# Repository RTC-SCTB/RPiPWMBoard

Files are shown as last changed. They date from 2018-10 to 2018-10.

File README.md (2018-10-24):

# RPiPWM_Board
## Описание
Проект платы расширения для одноплатного компьютера Raspberry Pi (версии B+, 2B, 3B, с 40 пинами).    
Включает в себя PCA9685 - I2C генератор ШИМ сигнала на 16 каналов, и либо одноканальным АЦП MCP3221, для измерения 
напряжения аккумулятора, либо измерителя питания INA219, который позволяет измерять также протекающий ток.  
Предусмотрен преобразователь напряжения LM2596-5.0 для питания Raspberry Pi от аккумулятора, 
номинальное напряжение питания до 25 В, при превышении возможен выход из строя некоторых (или всех) компонентов.  
Предусмотрено место для EEPROM CAT24C32 с обвязкой - для использования технологии 
[Raspberry Pi HAT](https://www.raspberrypi.org/blog/introducing-raspberry-pi-hats/), 
однако данная технология пока не используется.

## Содержание
- Необходимые нестандартные библиотеки - в папке `Libraries`  
- Список изменений - в файле `Changes.md`
- Gerber файлы - в папке `Gerbers`

## Функции

- Питание Raspberry Pi от аккумулятора (напряжение аккумулятора не должно превышать 25 В);
- Создание ШИМ сигнала на 16 каналах (0 - 15). Каналы 0 - 11 имеют возможность подключения внешнего источника питания
(предназначены для управления сервоприводами), каналы 12 - 15 предназначены для подключения драйверов, которые
 генерируют свое напряжение на данном разъеме;
- Определение напряжения питания (при подключении через клеммы), с помощью одноканального АЦП;
- Подключение I2C OLED дисплея SSD1306 размером 128x32 пикселя (может запаиваться на плату). Либо это посадочное место
может использоваться для подключения других I2C устройств при помощи разъема с шагом 2.54 мм;
- Кнопка и светодиод, подключенные к GPIO Raspberry Pi, функционал для которых может задаваться пользователем;

## Использование
Для данной платы написан [модуль](https://github.com/RTC-SCTB/RPiPWM) на языке Python 3,
реализующий весь перечисленный функционал.

## Полезные ссылки
- Даташит для ШИМ контроллера [PCA9685](https://cdn-shop.adafruit.com/datasheets/PCA9685.pdf)
- Даташит для дисплея [SSD1306](https://cdn-shop.adafruit.com/datasheets/SSD1306.pdf)
- Даташит для АЦП [MCP3221](http://ww1.microchip.com/downloads/en/DeviceDoc/20001732E.pdf)
- Даташит для измерителя питания [INA219](http://www.ti.com/lit/ds/symlink/ina219.pdf)

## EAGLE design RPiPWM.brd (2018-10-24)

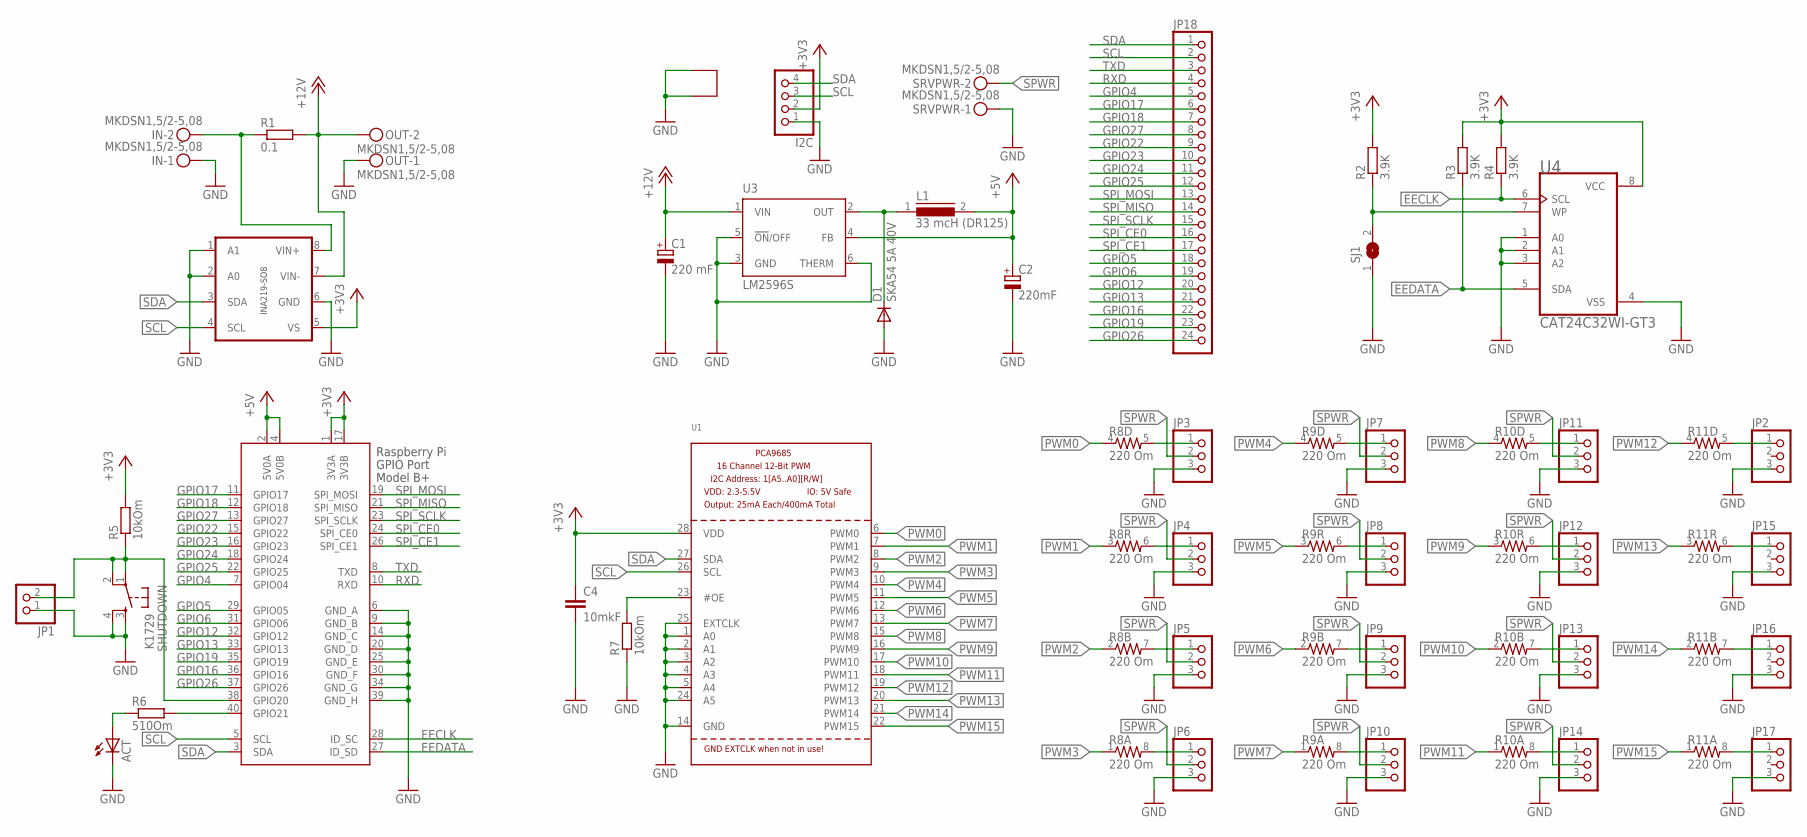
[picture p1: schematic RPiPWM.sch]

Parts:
ACT: LEDCHIPLED_1206; CHIPLED_1206
C1: 220 mF; 140CLH-1014
C2: 220mF; 140CLH-1014
C4: 10mkF; C0805K
D1: SKA54 5A 40V; SMB
GNDLOOP: LOOP
I2C: PINHD-1X04_2.54-S; 1X04-S
IN: MKDSN1,5/2-5,08
JP1: PINHD-1X02_2.54-S; 1X02-S
JP2, JP3, JP4, JP5, JP6, JP7, JP8, JP9, JP10, JP11, JP12, JP13, JP14, JP15, JP16, JP17: PINHD-1X03_2.54-S; 1X03-S
JP18: PINHD-1X24_2.54-S; 1X24-S
L1: 33 mcH (DR125); DR125
OUT: MKDSN1,5/2-5,08
R1: 0.1; R2512
R2, R3, R4: 3.9K; R0805
R5, R7: 10kOm; R0805
R6: 510Om; R0805
R8, R9, R10, R11: 220 Om; 0603-ARV
SHUTDOWN: K1729; DTSM-6
SJ1: SJ
SRVPWR: MKDSN1,5/2-5,08
U1: PCA9685; TSSOP28
U2: INA219-SO8D; SO08
U3: LM2596S; TO263-5
U4: CAT24C32WI-GT3; SOIC127P600X175-8N
X1: RASPI_BOARD_B+#_HDC; RASPI_BOARD_B+HAT_DF_CF

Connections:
+3V3: C4.1, I2C.2, R2.2, R3.2, R4.2, R5.2, U1.28 (VDD), U2.5 (VS), U4.8 (VCC), X1.1 (3V3A), X1.17 (3V3B)
+5V: C2.+, L1.2, U3.4 (FB), X1.2 (5V0A), X1.4 (5V0B)
+12V: C1.+, OUT.2, R1.2, U2.7 (VIN-), U3.1 (VIN)
EECLK: R4.1, U4.6 (SCL), X1.28 (ID_SC)
EEDATA: R3.1, U4.5 (SDA), X1.27 (ID_SD)
GND: ACT.C, C1.-, C2.-, C4.2, D1.A, GNDLOOP.P$1 (1), GNDLOOP.P$2 (2), I2C.1, IN.1, JP1.1, JP2.3, JP3.3, JP4.3, JP5.3, JP6.3, JP7.3, JP8.3, JP9.3, JP10.3, JP11.3, JP12.3, JP13.3, JP14.3, JP15.3, JP16.3, JP17.3, OUT.1, R7.1, SHUTDOWN.3, SHUTDOWN.4, SJ1.1, SRVPWR.1, U1.1 (A0), U1.2 (A1), U1.3 (A2), U1.4 (A3), U1.5 (A4), U1.14 (GND), U1.24 (A5), U1.25 (EXTCLK), U2.1 (A1), U2.2 (A0), U2.6 (GND), U3.3 (GND), U3.5 (!ON!/OFF), U3.6 (THERM), U4.1 (A0), U4.2 (A1), U4.3 (A2), U4.4 (VSS), X1.6 (GND_A), X1.9 (GND_B), X1.14 (GND_C), X1.20 (GND_D), X1.25 (GND_E), X1.30 (GND_F), X1.34 (GND_G), X1.39 (GND_H)
GPIO4: JP18.5, X1.7 (GPIO04)
GPIO5: JP18.18, X1.29 (GPIO05)
GPIO6: JP18.19, X1.31 (GPIO06)
GPIO12: JP18.20, X1.32 (GPIO12)
GPIO13: JP18.21, X1.33 (GPIO13)
GPIO16: JP18.22, X1.36 (GPIO16)
GPIO17: JP18.6, X1.11 (GPIO17)
GPIO18: JP18.7, X1.12 (GPIO18)
GPIO19: JP18.23, X1.35 (GPIO19)
GPIO22: JP18.9, X1.15 (GPIO22)
GPIO23: JP18.10, X1.16 (GPIO23)
GPIO24: JP18.11, X1.18 (GPIO24)
GPIO25: JP18.12, X1.22 (GPIO25)
GPIO26: JP18.24, X1.37 (GPIO26)
GPIO27: JP18.8, X1.13 (GPIO27)
unnamed: R6.2, X1.40 (GPIO21)
unnamed: ACT.A, R6.1
unnamed: D1.C, L1.1, U3.2 (OUT)
unnamed: JP1.2, R5.1, SHUTDOWN.1, SHUTDOWN.2, X1.38 (GPIO20)
unnamed: JP3.1, R8.5 (2)
unnamed: JP4.1, R8.6 (2)
unnamed: JP7.1, R9.5 (2)
unnamed: JP5.1, R8.7 (2)
unnamed: R2.1, SJ1.2, U4.7 (WP)
unnamed: JP6.1, R8.8 (2)
unnamed: JP11.1, R10.5 (2)
unnamed: JP2.1, R11.5 (2)
unnamed: JP15.1, R11.6 (2)
unnamed: JP16.1, R11.7 (2)
unnamed: JP17.1, R11.8 (2)
unnamed: JP14.1, R10.8 (2)
unnamed: JP13.1, R10.7 (2)
unnamed: JP12.1, R10.6 (2)
unnamed: JP8.1, R9.6 (2)
unnamed: JP9.1, R9.7 (2)
unnamed: JP10.1, R9.8 (2)
unnamed: IN.2, R1.1, U2.8 (VIN+)
unnamed: R7.2, U1.23 (#OE)
PWM0: R8.4 (1), U1.6 (PWM0)
PWM1: R8.3 (1), U1.7 (PWM1)
PWM2: R8.2 (1), U1.8 (PWM2)
PWM3: R8.1, U1.9 (PWM3)
PWM4: R9.4 (1), U1.10 (PWM4)
PWM5: R9.3 (1), U1.11 (PWM5)
PWM6: R9.2 (1), U1.12 (PWM6)
PWM7: R9.1, U1.13 (PWM7)
PWM8: R10.4 (1), U1.15 (PWM8)
PWM9: R10.3 (1), U1.16 (PWM9)
PWM10: R10.2 (1), U1.17 (PWM10)
PWM11: R10.1, U1.18 (PWM11)
PWM12: R11.4 (1), U1.19 (PWM12)
PWM13: R11.3 (1), U1.20 (PWM13)
PWM14: R11.2 (1), U1.21 (PWM14)
PWM15: R11.1, U1.22 (PWM15)
RXD: JP18.4, X1.10 (RXD)
SCL: I2C.3, JP18.2, U1.26 (SCL), U2.4 (SCL), X1.5 (SCL)
SDA: I2C.4, JP18.1, U1.27 (SDA), U2.3 (SDA), X1.3 (SDA)
SPI_CE0: JP18.16, X1.24 (SPI_CE0)
SPI_CE1: JP18.17, X1.26 (SPI_CE1)
SPI_MISO: JP18.14, X1.21 (SPI_MISO)
SPI_MOSI: JP18.13, X1.19 (SPI_MOSI)
SPI_SCLK: JP18.15, X1.23 (SPI_SCLK)
SPWR: JP3.2, JP4.2, JP5.2, JP6.2, JP7.2, JP8.2, JP9.2, JP10.2, JP11.2, JP12.2, JP13.2, JP14.2, SRVPWR.2
TXD: JP18.3, X1.8 (TXD)

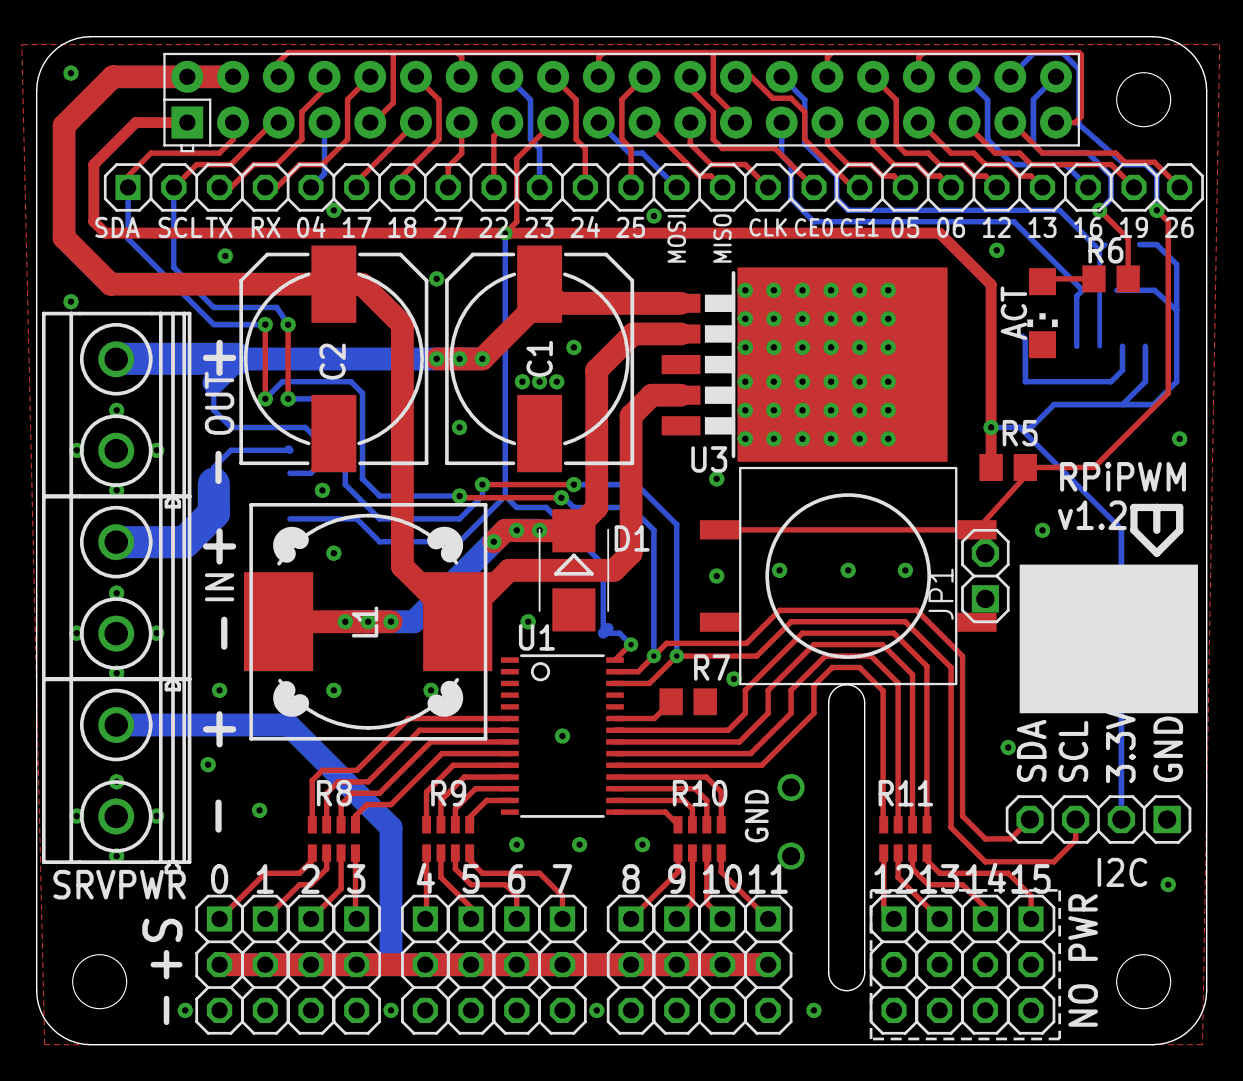
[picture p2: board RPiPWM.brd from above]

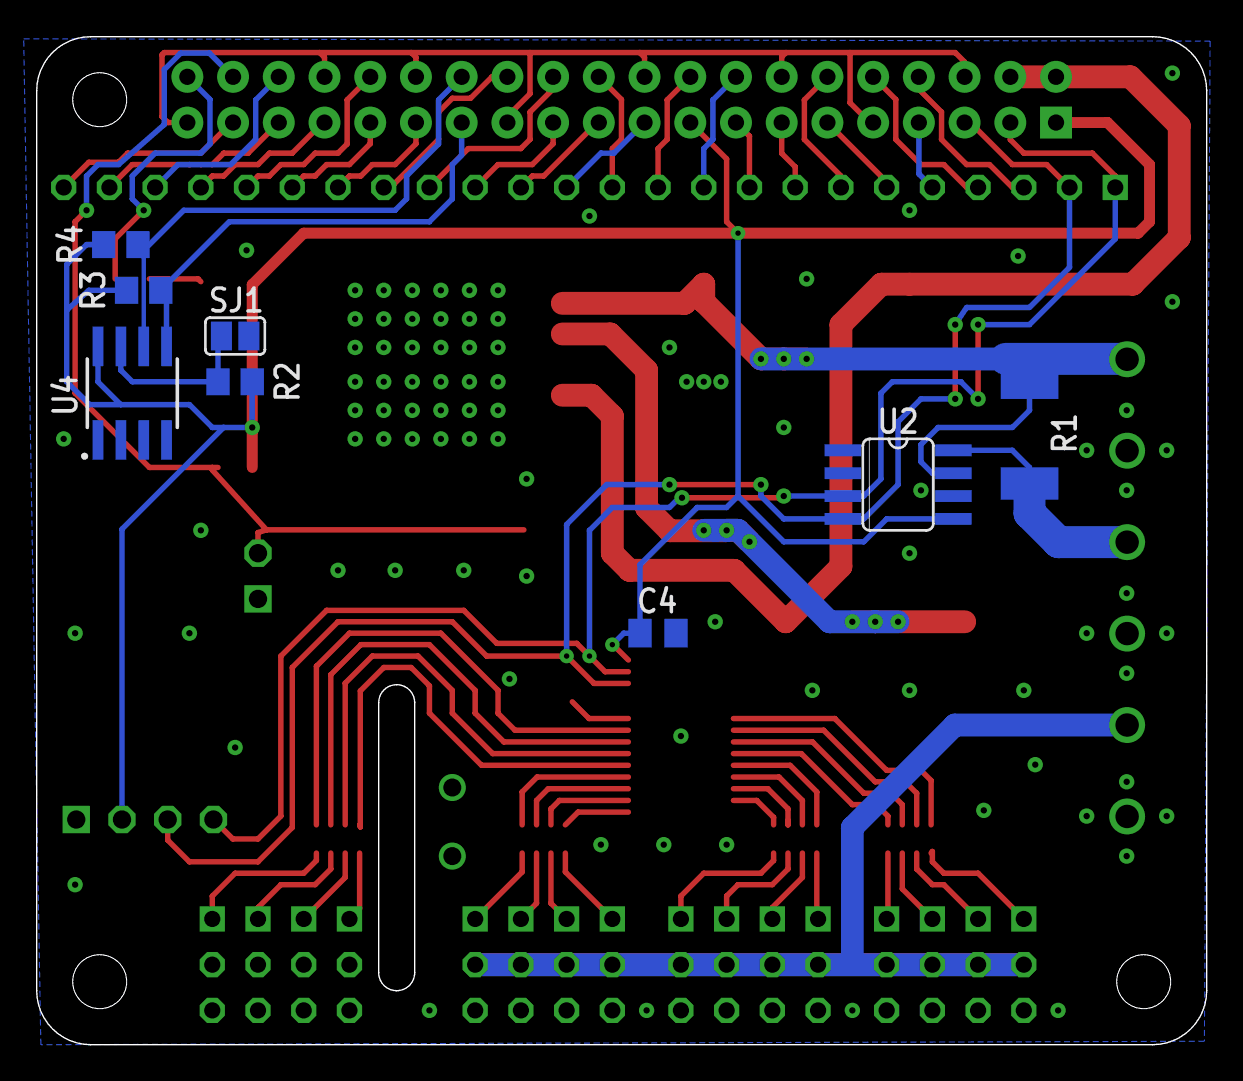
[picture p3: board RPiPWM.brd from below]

Board: 2 copper layers, 65.0 x 56.0 mm, 48 parts (8 on the bottom side), 70 nets.

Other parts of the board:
U$1: MASKLABEL

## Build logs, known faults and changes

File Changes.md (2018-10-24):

**Изменения в версии 1.2:**
- Заменен однокональный АЦП MCP3221 на измеритель питания INA219, теперь измеряются одновременно и напряжение,
 и потребляемый ток;
- Добавлен разъем выхода питания (чтобы измерять потребление всех компонентов робота);
- Все три разъема питания (вход питания платы, выход питания, вход питания серв) теперь состыкованы 
для удобства монтажа;
- Передвинута петля GND (для подключения земли осциллографа), чтобы было удобнее к ней подключаться;
- Подписи +- разъемов питания теперь с верхней стороны платы;

**Изменения в версии 1.1:**
- Заменены конденсаторы у преобразователя напряжения (теперь оба - smd электролиты);
- Исправлен шаг между пинами I2C разъема для дисплея (был 2 мм, теперь 2.54 мм);
- Увеличен размер всех подписей на шелкографии;
- Изменен библиотечный элемент кнопки - убрана  асимметрия;
- Исправлен пад под диодом шоттки (с smc на smb - он стал меньше);
- Увеличины пады под резисторными сборками 0603 в полтора раза;
- Добавлена подпись к разъемам ШИМ (отмечены S, +, -);

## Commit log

2018-10-24 Обновлены README и Changes
2018-10-24 Добавлены Gerber файлы
    [copper_bottom.gbr, copper_top.gbr, drill.gbr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]
2018-10-24 Исправлен файл для сверловки платы
    [drill.gbr, drills.xln]

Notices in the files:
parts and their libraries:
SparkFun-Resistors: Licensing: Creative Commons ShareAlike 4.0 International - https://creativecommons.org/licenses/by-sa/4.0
